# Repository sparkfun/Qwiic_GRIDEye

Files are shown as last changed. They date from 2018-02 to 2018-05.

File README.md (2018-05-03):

SparkFun Qwiic Panasonic Grid-EYE Infrared Array AMG88xx
========================================

SparkFun Grid-EYE Infrared Array Breakout - AMG8833 (Qwiic)

[*SparkFun Grid-EYE Infrared Array Breakout - AMG8833 (Qwiic) (SEN-14607)*](https://www.sparkfun.com/products/14607)

The GridEYE from Panasonic is a 8 by 8 thermopile array. This means you have an array of 64 pixels each capable of detecting temperature remotely. It’s like having thermal camera (or Predator’s vision) just in really low resolution. The SparkFun Grid-EYE Qwiic carrier board utilizes the high performance, high gain 3.3V AMG88 sensor. Do not hook 5V to this beast! Better yet, use the Qwiic system - it makes it much easier and quicker to get started.

The SparkFun carrier board incorporates all the needed passive components as well as a jumper to change the I2C address and a jumper to remove the pull up resistors if needed.

Repository Contents
-------------------

* **/Documents** - Datasheets
* **/Hardware** - Eagle design files (.brd, .sch)

Documentation
--------------
* **[Arduino Library](https://github.com/sparkfun/SparkFun_GridEYE_Arduino_Library)** - Library for reading the sensor and outputing fun graphics over the serial port
* **[Hookup Guide](https://learn.sparkfun.com/tutorials/qwiic-grid-eye-infrared-array-amg88xx-hookup-guide)** - Basic hookup guide for the Qwiic GRID-Eye Infrared Array.

Product Versions
----------------
* [SEN-14607](https://www.sparkfun.com/products/14607)- SparkFun breakout board for Grid-EYE AMG8833
* [SPX-14568](https://www.sparkfun.com/products/14568)- SparkX breakout board for Grid-EYE AMG8833

License Information
-------------------

This product is _**open source**_! 

Please review the LICENSE.md file for license information. 

If you have any questions or concerns on licensing, please contact techsupport@sparkfun.com.

Please use, reuse, and modify these files as you see fit. Please maintain attribution to SparkFun Electronics and release anyThing Development Board derivative under the same license.

Distributed as-is; no warranty is given.

- Your friends at SparkFun.

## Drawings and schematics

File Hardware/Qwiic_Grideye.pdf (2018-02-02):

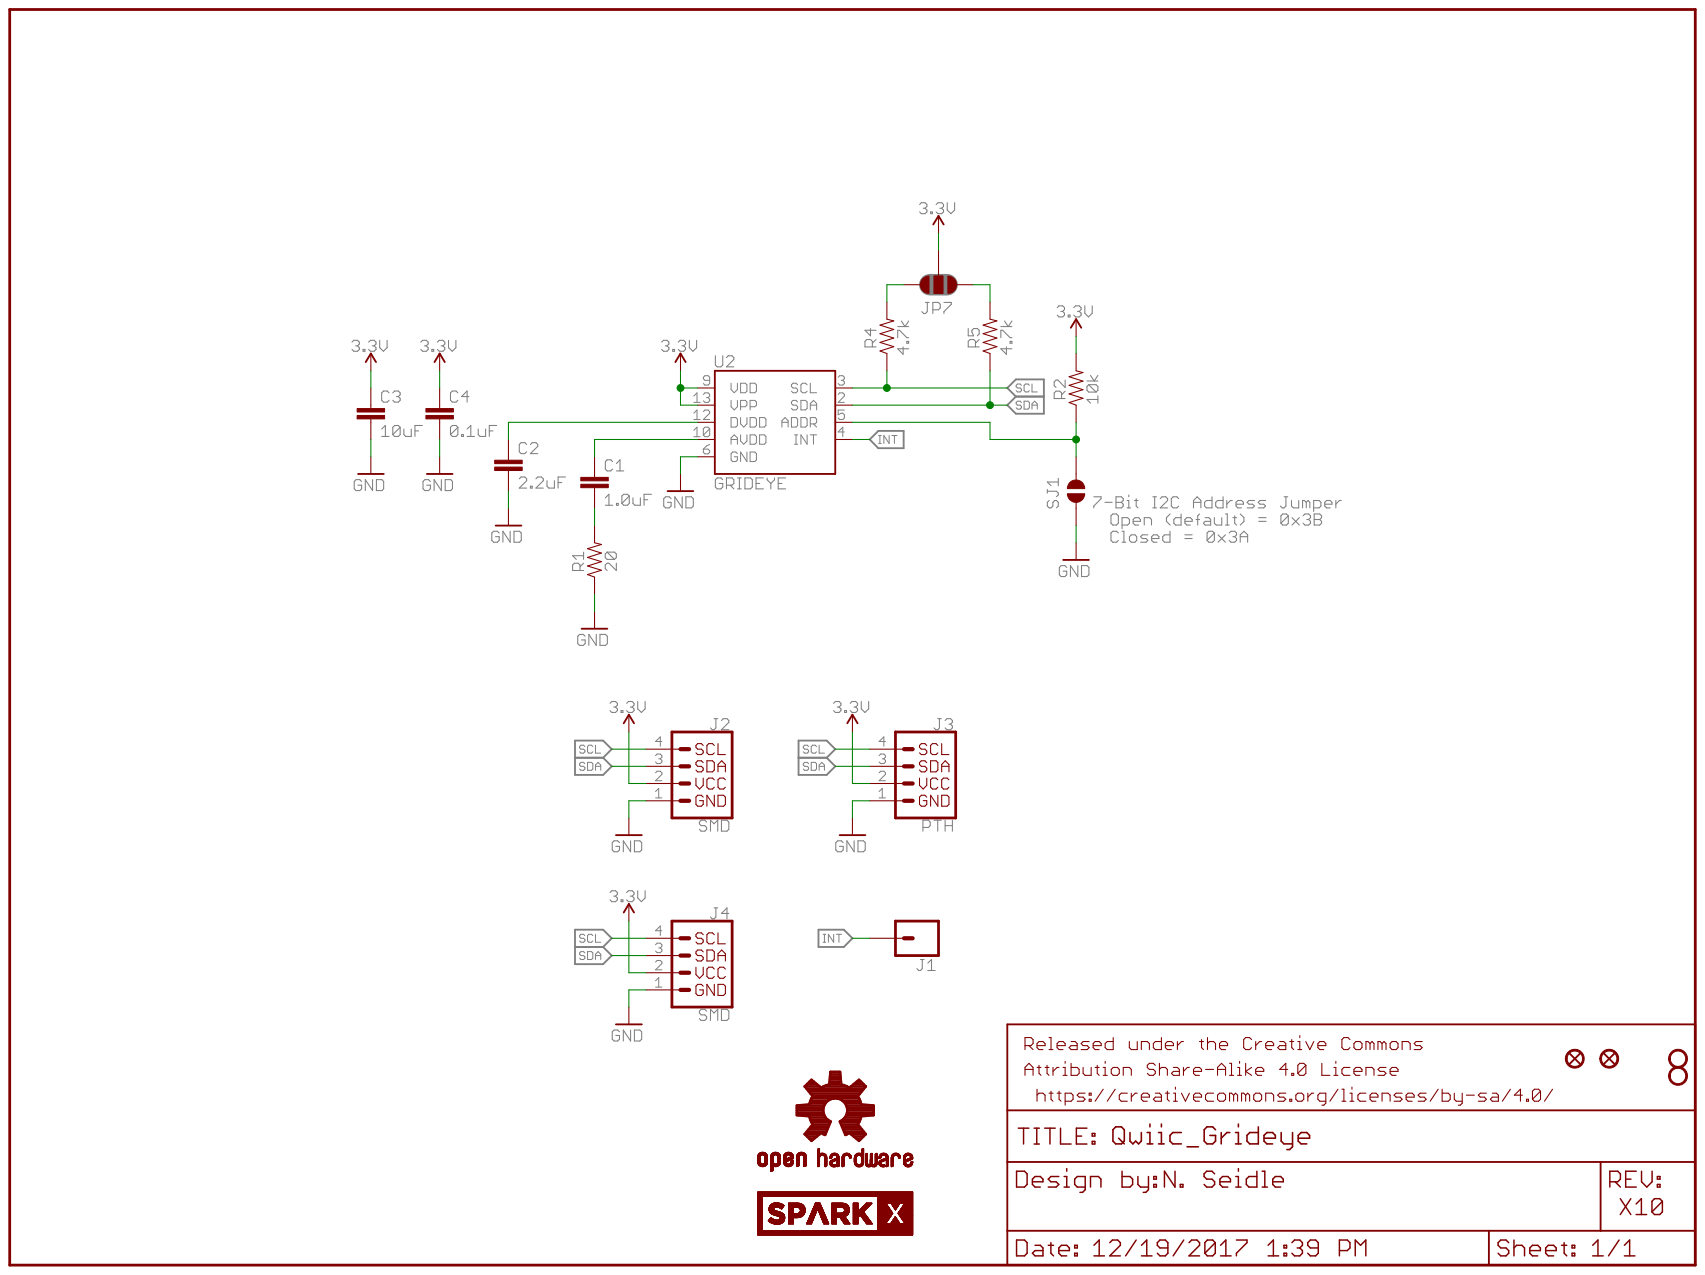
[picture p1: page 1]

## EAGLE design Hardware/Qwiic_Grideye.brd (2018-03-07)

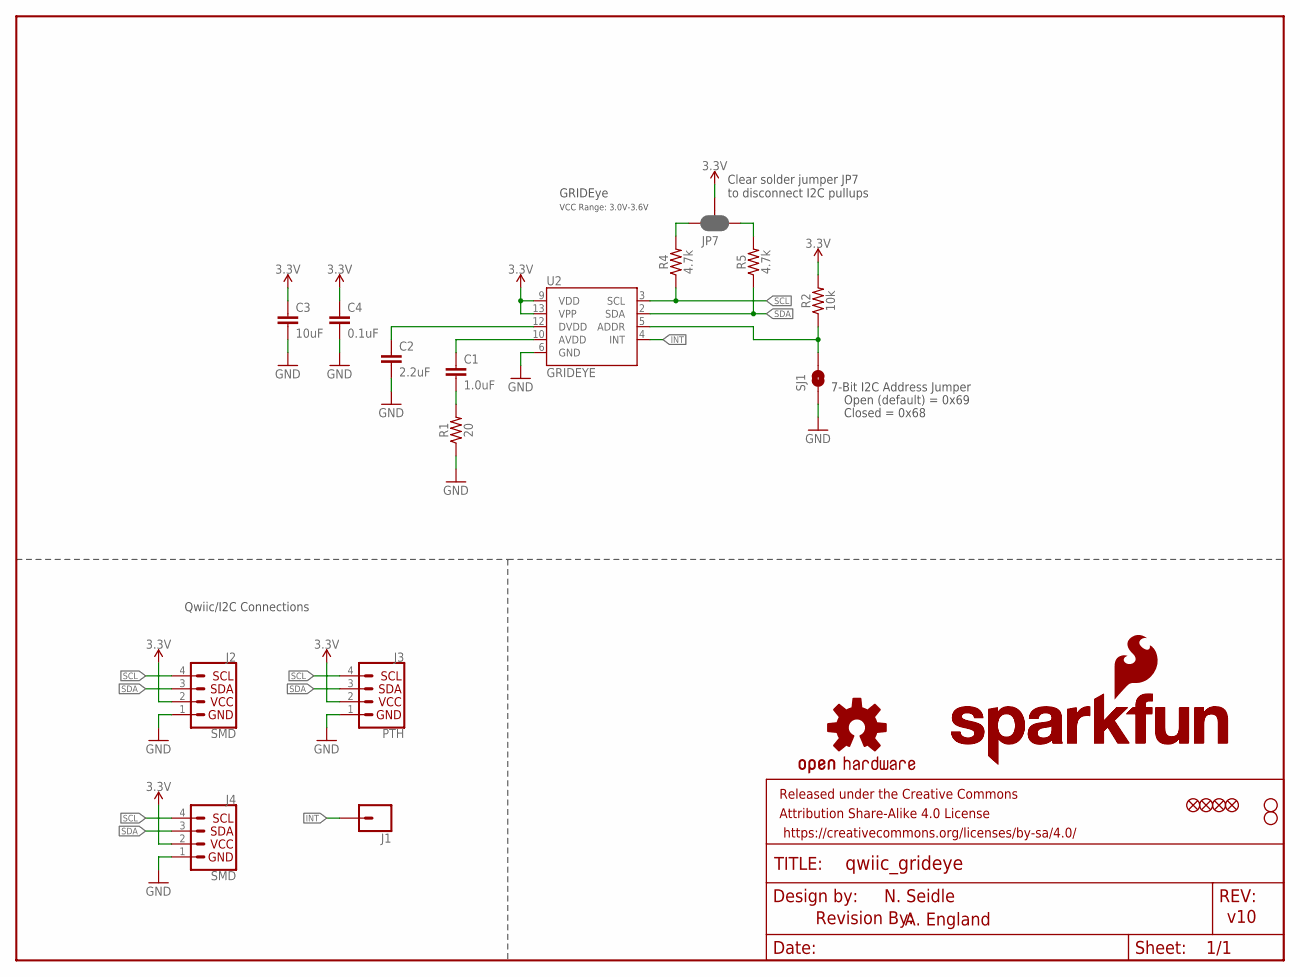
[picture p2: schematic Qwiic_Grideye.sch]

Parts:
C1: 1.0uF; 0603
C2: 2.2uF; 0603
C3: 10uF; 0603
C4: 0.1uF; 0603
FRAME1: FRAME-LETTER; CREATIVE_COMMONS
J1: CONN_01PTH_NO_SILK_YES_STOP; 1X01_NO_SILK
J2, J4: SMD; 1X04_1MM_RA
J3: PTH; 1X04_NO_SILK
JP1, JP2, JP5, JP6: FIDUCIALUFIDUCIAL; MICRO-FIDUCIAL
JP3, JP4: STAND-OFF
JP7: JUMPER-SMT_3_2-NC_PASTE_SILK; SMT-JUMPER_3_2-NC_PASTE_SILK
LOGO1: OSHW-LOGOMINI; OSHW-LOGO-MINI
LOGO2: REVISION
R1: 20; 0603
R2: 10k; 0603
R4, R5: 4.7k; 0603
SJ1: SOLDERJUMPERNO; SJ_2S-NO
U2: GRIDEYE; GRIDEYE-AMG88
U$1: SFE_LOGO_NAME.1_INCH; SFE_LOGO_NAME_.1
U$2: SFE_LOGO_NAME_FLAME.1_INCH; SFE_LOGO_NAME_FLAME_.1

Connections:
3.3V: C3.1, C4.1, J2.2 (VCC), J3.2 (VCC), J4.2 (VCC), JP7.2, R2.2, U2.9 (VDD), U2.13 (VPP)
ADDR: R2.1, SJ1.2, U2.5 (ADDR)
GND: C2.2, C3.2, C4.2, J2.1 (GND), J3.1 (GND), J4.1 (GND), R1.1, SJ1.1, U2.6 (GND)
INT: J1.1, U2.4 (INT)
unnamed: JP7.1, R5.2
unnamed: JP7.3, R4.2
unnamed: C2.1, U2.12 (DVDD)
unnamed: C1.1, U2.10 (AVDD)
unnamed: C1.2, R1.2
SCL: J2.4 (SCL), J3.4 (SCL), J4.4 (SCL), R4.1, U2.3 (SCL)
SDA: J2.3 (SDA), J3.3 (SDA), J4.3 (SDA), R5.1, U2.2 (SDA)

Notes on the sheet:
7-Bit I2C Address Jumper
Closed = 0x68
Open (default) = 0x69
N. Seidle
v10
GRIDEye
Clear solder jumper JP7 to disconnect I2C pullups
Qwiic/I2C Connections
A. England
VCC Range: 3.0V-3.6V

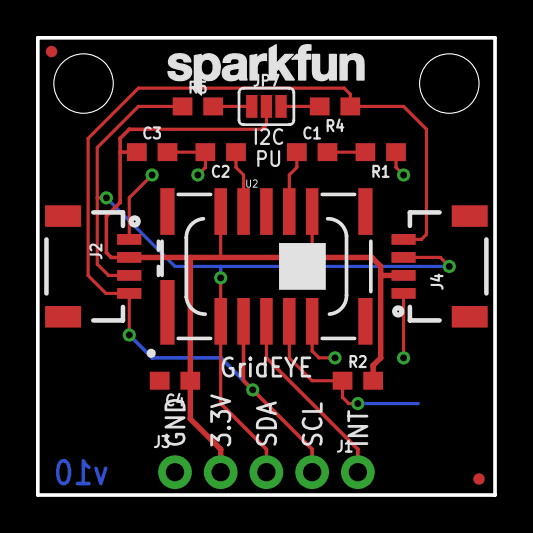
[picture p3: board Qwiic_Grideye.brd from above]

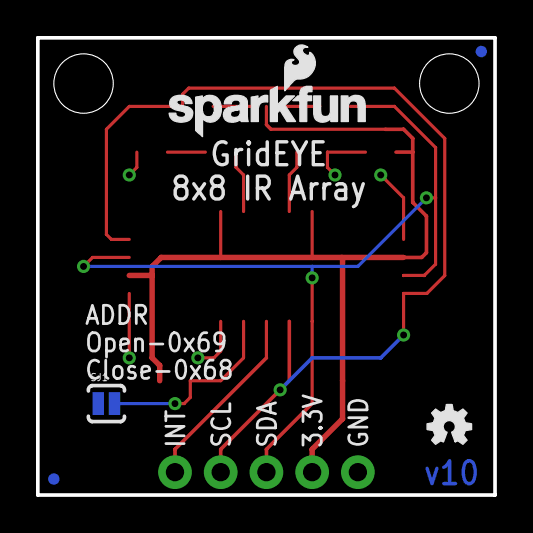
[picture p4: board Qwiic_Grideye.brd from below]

Board: 2 copper layers, 25.4 x 25.4 mm, 26 parts (5 on the bottom side), 11 nets.

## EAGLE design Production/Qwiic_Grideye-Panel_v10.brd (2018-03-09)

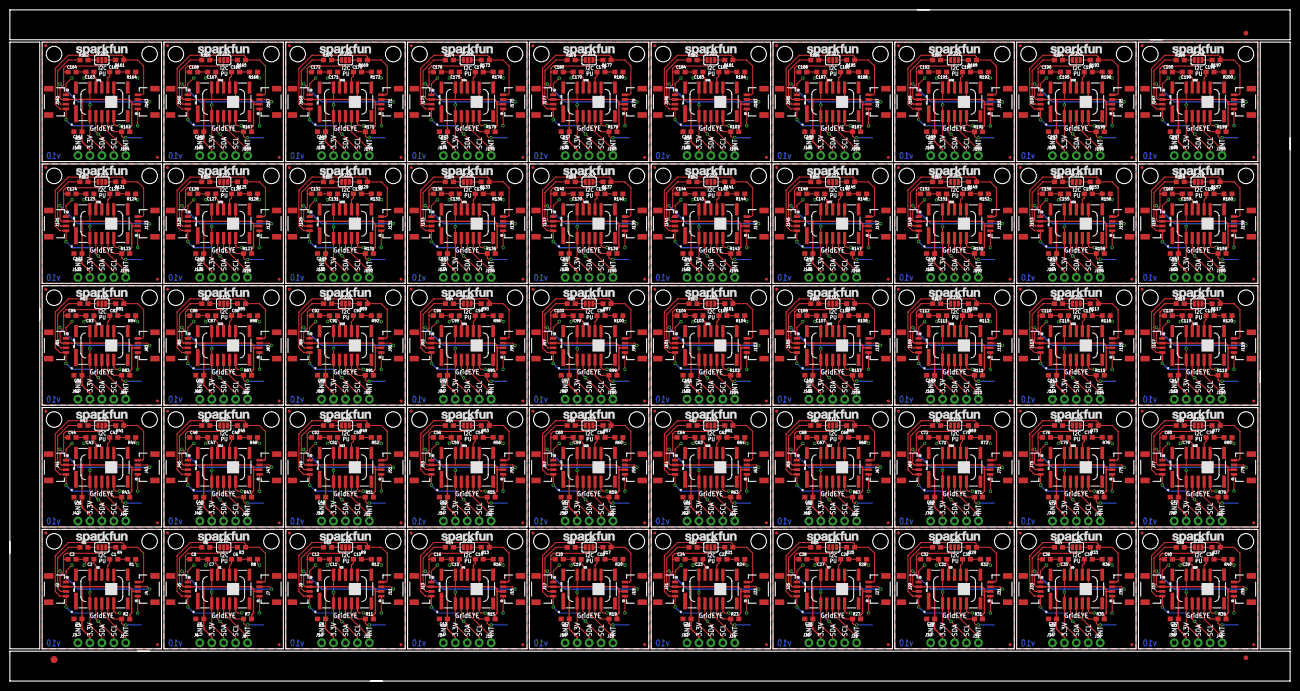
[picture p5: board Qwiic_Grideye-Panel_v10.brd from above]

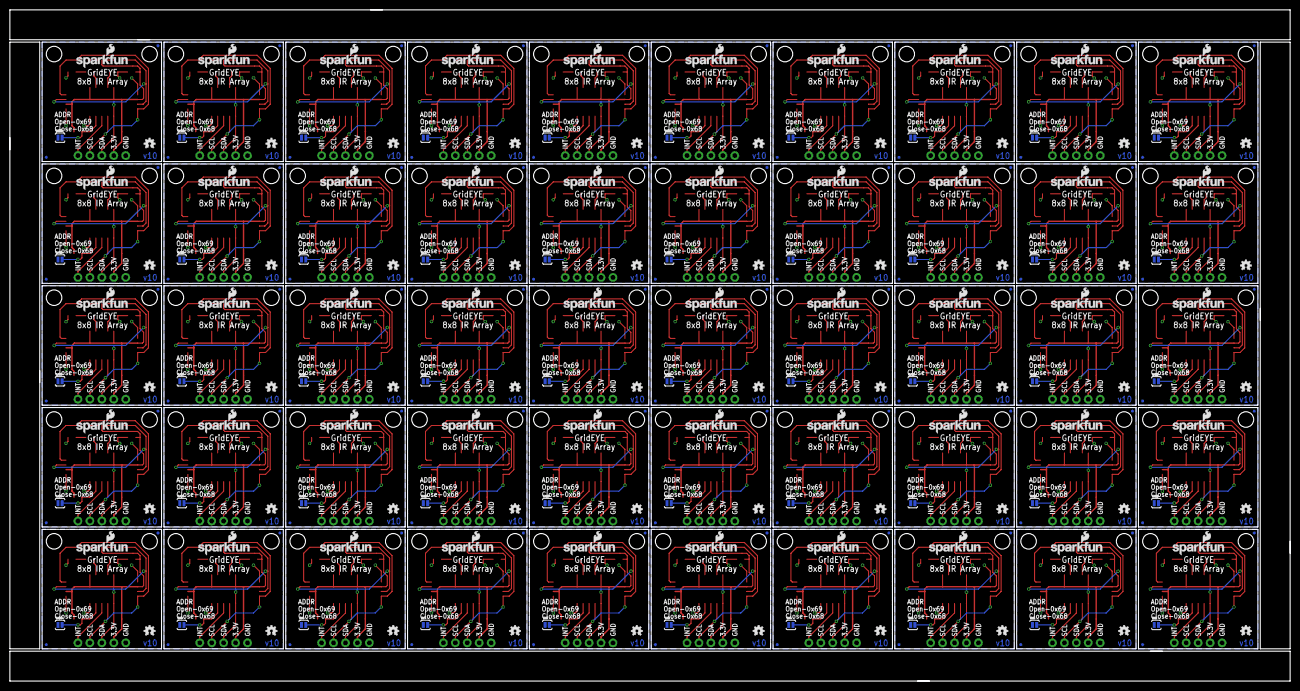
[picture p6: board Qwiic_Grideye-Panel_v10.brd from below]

Board: 2 copper layers, 272.3 x 142.7 mm, 1203 parts (250 on the bottom side), 550 nets.

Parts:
C1, C6, C10, C14, C18, C22, C26, C30, C34, C38, C42, C46, C50, C54, C58, C62, C66, C70, C74, C78, C82, C86, C90, C94, C98, C102, C106, C110, C114, C118, C122, C126, C130, C134, C138, C142, C146, C150, C154, C158, C162, C166, C170, C174, C178, C182, C186, C190, C194, C198: 1.0uF; 0603
C2, C7, C11, C15, C19, C23, C27, C31, C35, C39, C43, C47, C51, C55, C59, C63, C67, C71, C75, C79, C83, C87, C91, C95, C99, C103, C107, C111, C115, C119, C123, C127, C131, C135, C139, C143, C147, C151, C155, C159, C163, C167, C171, C175, C179, C183, C187, C191, C195, C199: 2.2uF; 0603
C3, C8, C12, C16, C20, C24, C28, C32, C36, C40, C44, C48, C52, C56, C60, C64, C68, C72, C76, C80, C84, C88, C92, C96, C100, C104, C108, C112, C116, C120, C124, C128, C132, C136, C140, C144, C148, C152, C156, C160, C164, C168, C172, C176, C180, C184, C188, C192, C196, C200: 10uF; 0603
C4, C5, C9, C13, C17, C21, C25, C29, C33, C37, C41, C45, C49, C53, C57, C61, C65, C69, C73, C77, C81, C85, C89, C93, C97, C101, C105, C109, C113, C117, C121, C125, C129, C133, C137, C141, C145, C149, C153, C157, C161, C165, C169, C173, C177, C181, C185, C189, C193, C197: 0.1uF; 0603
E$1: FIDUCIAL-1.5X3
E$5, E$8: FIDUCIAL-1X2
J1, J8, J12, J16, J20, J24, J28, J32, J36, J40, J44, J48, J52, J56, J60, J64, J68, J72, J76, J80, J84, J88, J92, J96, J100, J104, J108, J112, J116, J120, J124, J128, J132, J136, J140, J144, J148, J152, J156, J160, J164, J168, J172, J176, J180, J184, J188, J192, J196, J200: 1X01_NO_SILK
J2, J4, J5, J7, J9, J11, J13, J15, J17, J19, J21, J23, J25, J27, J29, J31, J33, J35, J37, J39, J41, J43, J45, J47, J49, J51, J53, J55, J57, J59, J61, J63, J65, J67, J69, J71, J73, J75, J77, J79, J81, J83, J85, J87, J89, J91, J93, J95, J97, J99, J101, J103, J105, J107, J109, J111, J113, J115, J117, J119, J121, J123, J125, J127, J129, J131, J133, J135, J137, J139, J141, J143, J145, J147, J149, J151, J153, J155, J157, J159, J161, J163, J165, J167, J169, J171, J173, J175, J177, J179, J181, J183, J185, J187, J189, J191, J193, J195, J197, J199: SMD; 1X04_1MM_RA
J3, J6, J10, J14, J18, J22, J26, J30, J34, J38, J42, J46, J50, J54, J58, J62, J66, J70, J74, J78, J82, J86, J90, J94, J98, J102, J106, J110, J114, J118, J122, J126, J130, J134, J138, J142, J146, J150, J154, J158, J162, J166, J170, J174, J178, J182, J186, J190, J194, J198: PTH; 1X04_NO_SILK
JP1, JP2, JP5, JP6, JP10, JP11, JP13, JP14, JP17, JP18, JP20, JP21, JP24, JP25, JP27, JP28, JP31, JP32, JP34, JP35, JP38, JP39, JP41, JP42, JP45, JP46, JP48, JP49, JP52, JP53, JP55, JP56, JP59, JP60, JP62, JP63, JP66, JP67, JP69, JP70, JP73, JP74, JP76, JP77, JP80, JP81, JP83, JP84, JP87, JP88, JP90, JP91, JP94, JP95, JP97, JP98, JP101, JP102, JP104, JP105, JP108, JP109, JP111, JP112, JP115, JP116, JP118, JP119, JP122, JP123, JP125, JP126, JP129, JP130, JP132, JP133, JP136, JP137, JP139, JP140, JP143, JP144, JP146, JP147, JP150, JP151, JP153, JP154, JP157, JP158, JP160, JP161, JP164, JP165, JP167, JP168, JP171, JP172, JP174, JP175, JP178, JP179, JP181, JP182, JP185, JP186, JP188, JP189, JP192, JP193, JP195, JP196, JP199, JP200, JP202, JP203, JP206, JP207, JP209, JP210, JP213, JP214, JP216, JP217, JP220, JP221, JP223, JP224, JP227, JP228, JP230, JP231, JP234, JP235, JP237, JP238, JP241, JP242, JP244, JP245, JP248, JP249, JP251, JP252, JP255, JP256, JP258, JP259, JP262, JP263, JP265, JP266, JP269, JP270, JP272, JP273, JP276, JP277, JP279, JP280, JP283, JP284, JP286, JP287, JP290, JP291, JP293, JP294, JP297, JP298, JP300, JP301, JP304, JP305, JP307, JP308, JP311, JP312, JP314, JP315, JP318, JP319, JP321, JP322, JP325, JP326, JP328, JP329, JP332, JP333, JP335, JP336, JP339, JP340, JP342, JP343, JP346, JP347, JP349, JP350: FIDUCIALUFIDUCIAL; MICRO-FIDUCIAL
JP3, JP4, JP8, JP9, JP15, JP16, JP22, JP23, JP29, JP30, JP36, JP37, JP43, JP44, JP50, JP51, JP57, JP58, JP64, JP65, JP71, JP72, JP78, JP79, JP85, JP86, JP92, JP93, JP99, JP100, JP106, JP107, JP113, JP114, JP120, JP121, JP127, JP128, JP134, JP135, JP141, JP142, JP148, JP149, JP155, JP156, JP162, JP163, JP169, JP170, JP176, JP177, JP183, JP184, JP190, JP191, JP197, JP198, JP204, JP205, JP211, JP212, JP218, JP219, JP225, JP226, JP232, JP233, JP239, JP240, JP246, JP247, JP253, JP254, JP260, JP261, JP267, JP268, JP274, JP275, JP281, JP282, JP288, JP289, JP295, JP296, JP302, JP303, JP309, JP310, JP316, JP317, JP323, JP324, JP330, JP331, JP337, JP338, JP344, JP345: STAND-OFF
JP7, JP12, JP19, JP26, JP33, JP40, JP47, JP54, JP61, JP68, JP75, JP82, JP89, JP96, JP103, JP110, JP117, JP124, JP131, JP138, JP145, JP152, JP159, JP166, JP173, JP180, JP187, JP194, JP201, JP208, JP215, JP222, JP229, JP236, JP243, JP250, JP257, JP264, JP271, JP278, JP285, JP292, JP299, JP306, JP313, JP320, JP327, JP334, JP341, JP348: SMT-JUMPER_3_2-NC_PASTE_SILK
LOGO1, LOGO2, LOGO3, LOGO4, LOGO5, LOGO6, LOGO7, LOGO8, LOGO9, LOGO10, LOGO11, LOGO12, LOGO13, LOGO14, LOGO15, LOGO16, LOGO17, LOGO18, LOGO19, LOGO20, LOGO21, LOGO22, LOGO23, LOGO24, LOGO25, LOGO26, LOGO27, LOGO28, LOGO29, LOGO30, LOGO31, LOGO32, LOGO33, LOGO34, LOGO35, LOGO36, LOGO37, LOGO38, LOGO39, LOGO40, LOGO41, LOGO42, LOGO43, LOGO44, LOGO45, LOGO46, LOGO47, LOGO48, LOGO49, LOGO50: OSHW-LOGOMINI; OSHW-LOGO-MINI
R1, R8, R12, R16, R20, R24, R28, R32, R36, R40, R44, R48, R52, R56, R60, R64, R68, R72, R76, R80, R84, R88, R92, R96, R100, R104, R108, R112, R116, R120, R124, R128, R132, R136, R140, R144, R148, R152, R156, R160, R164, R168, R172, R176, R180, R184, R188, R192, R196, R200: 20; 0603
R2, R7, R11, R15, R19, R23, R27, R31, R35, R39, R43, R47, R51, R55, R59, R63, R67, R71, R75, R79, R83, R87, R91, R95, R99, R103, R107, R111, R115, R119, R123, R127, R131, R135, R139, R143, R147, R151, R155, R159, R163, R167, R171, R175, R179, R183, R187, R191, R195, R199: 10k; 0603
R3, R4, R5, R6, R9, R10, R13, R14, R17, R18, R21, R22, R25, R26, R29, R30, R33, R34, R37, R38, R41, R42, R45, R46, R49, R50, R53, R54, R57, R58, R61, R62, R65, R66, R69, R70, R73, R74, R77, R78, R81, R82, R85, R86, R89, R90, R93, R94, R97, R98, R101, R102, R105, R106, R109, R110, R113, R114, R117, R118, R121, R122, R125, R126, R129, R130, R133, R134, R137, R138, R141, R142, R145, R146, R149, R150, R153, R154, R157, R158, R161, R162, R165, R166, R169, R170, R173, R174, R177, R178, R181, R182, R185, R186, R189, R190, R193, R194, R197, R198: 4.7k; 0603
SJ1, SJ2, SJ3, SJ4, SJ5, SJ6, SJ7, SJ8, SJ9, SJ10, SJ11, SJ12, SJ13, SJ14, SJ15, SJ16, SJ17, SJ18, SJ19, SJ20, SJ21, SJ22, SJ23, SJ24, SJ25, SJ26, SJ27, SJ28, SJ29, SJ30, SJ31, SJ32, SJ33, SJ34, SJ35, SJ36, SJ37, SJ38, SJ39, SJ40, SJ41, SJ42, SJ43, SJ44, SJ45, SJ46, SJ47, SJ48, SJ49, SJ50: SJ_2S-NO
U1, U2, U3, U4, U5, U6, U7, U8, U9, U10, U11, U12, U13, U14, U15, U16, U17, U18, U19, U20, U21, U22, U23, U24, U25, U26, U27, U28, U29, U30, U31, U32, U33, U34, U35, U36, U37, U38, U39, U40, U41, U42, U43, U44, U45, U46, U47, U48, U49, U50: GRIDEYE; GRIDEYE-AMG88
U$1, U$4, U$6, U$8, U$10, U$12, U$14, U$16, U$18, U$20, U$22, U$24, U$26, U$28, U$30, U$32, U$34, U$36, U$38, U$40, U$42, U$44, U$46, U$48, U$50, U$52, U$54, U$56, U$58, U$60, U$62, U$64, U$66, U$68, U$70, U$72, U$74, U$76, U$78, U$80, U$82, U$84, U$86, U$88, U$90, U$92, U$94, U$96, U$98, U$100: SFE_LOGO_NAME.1_INCH; SFE_LOGO_NAME_.1
U$2, U$3, U$5, U$7, U$9, U$11, U$13, U$15, U$17, U$19, U$21, U$23, U$25, U$27, U$29, U$31, U$33, U$35, U$37, U$39, U$41, U$43, U$45, U$47, U$49, U$51, U$53, U$55, U$57, U$59, U$61, U$63, U$65, U$67, U$69, U$71, U$73, U$75, U$77, U$79, U$81, U$83, U$85, U$87, U$89, U$91, U$93, U$95, U$97, U$99: SFE_LOGO_NAME_FLAME.1_INCH; SFE_LOGO_NAME_FLAME_.1

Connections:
3.3V: C3.1, C4.1, J2.2, J3.2, J4.2, JP7.2, R2.2, U2.9, U2.13
3.3V1: C5.1, C8.1, J5.2, J6.2, J7.2, JP12.2, R7.2, U1.9, U1.13
3.3V2: C9.1, C12.1, J9.2, J10.2, J11.2, JP19.2, R11.2, U3.9, U3.13
3.3V3: C13.1, C16.1, J13.2, J14.2, J15.2, JP26.2, R15.2, U4.9, U4.13
3.3V4: C17.1, C20.1, J17.2, J18.2, J19.2, JP33.2, R19.2, U5.9, U5.13
3.3V5: C21.1, C24.1, J21.2, J22.2, J23.2, JP40.2, R23.2, U6.9, U6.13
3.3V6: C25.1, C28.1, J25.2, J26.2, J27.2, JP47.2, R27.2, U7.9, U7.13
3.3V7: C29.1, C32.1, J29.2, J30.2, J31.2, JP54.2, R31.2, U8.9, U8.13
3.3V8: C33.1, C36.1, J33.2, J34.2, J35.2, JP61.2, R35.2, U9.9, U9.13
3.3V9: C37.1, C40.1, J37.2, J38.2, J39.2, JP68.2, R39.2, U10.9, U10.13
3.3V10: C41.1, C44.1, J41.2, J42.2, J43.2, JP75.2, R43.2, U11.9, U11.13
3.3V11: C45.1, C48.1, J45.2, J46.2, J47.2, JP82.2, R47.2, U12.9, U12.13
3.3V12: C49.1, C52.1, J49.2, J50.2, J51.2, JP89.2, R51.2, U13.9, U13.13
3.3V13: C53.1, C56.1, J53.2, J54.2, J55.2, JP96.2, R55.2, U14.9, U14.13
3.3V14: C57.1, C60.1, J57.2, J58.2, J59.2, JP103.2, R59.2, U15.9, U15.13
3.3V15: C61.1, C64.1, J61.2, J62.2, J63.2, JP110.2, R63.2, U16.9, U16.13
3.3V16: C65.1, C68.1, J65.2, J66.2, J67.2, JP117.2, R67.2, U17.9, U17.13
3.3V17: C69.1, C72.1, J69.2, J70.2, J71.2, JP124.2, R71.2, U18.9, U18.13
3.3V18: C73.1, C76.1, J73.2, J74.2, J75.2, JP131.2, R75.2, U19.9, U19.13
3.3V19: C77.1, C80.1, J77.2, J78.2, J79.2, JP138.2, R79.2, U20.9, U20.13
3.3V20: C81.1, C84.1, J81.2, J82.2, J83.2, JP145.2, R83.2, U21.9, U21.13
3.3V21: C85.1, C88.1, J85.2, J86.2, J87.2, JP152.2, R87.2, U22.9, U22.13
3.3V22: C89.1, C92.1, J89.2, J90.2, J91.2, JP159.2, R91.2, U23.9, U23.13
3.3V23: C93.1, C96.1, J93.2, J94.2, J95.2, JP166.2, R95.2, U24.9, U24.13
3.3V24: C97.1, C100.1, J97.2, J98.2, J99.2, JP173.2, R99.2, U25.9, U25.13
3.3V25: C101.1, C104.1, J101.2, J102.2, J103.2, JP180.2, R103.2, U26.9, U26.13
3.3V26: C105.1, C108.1, J105.2, J106.2, J107.2, JP187.2, R107.2, U27.9, U27.13
3.3V27: C109.1, C112.1, J109.2, J110.2, J111.2, JP194.2, R111.2, U28.9, U28.13
3.3V28: C113.1, C116.1, J113.2, J114.2, J115.2, JP201.2, R115.2, U29.9, U29.13
3.3V29: C117.1, C120.1, J117.2, J118.2, J119.2, JP208.2, R119.2, U30.9, U30.13
3.3V30: C121.1, C124.1, J121.2, J122.2, J123.2, JP215.2, R123.2, U31.9, U31.13
3.3V31: C125.1, C128.1, J125.2, J126.2, J127.2, JP222.2, R127.2, U32.9, U32.13
3.3V32: C129.1, C132.1, J129.2, J130.2, J131.2, JP229.2, R131.2, U33.9, U33.13
3.3V33: C133.1, C136.1, J133.2, J134.2, J135.2, JP236.2, R135.2, U34.9, U34.13
3.3V34: C137.1, C140.1, J137.2, J138.2, J139.2, JP243.2, R139.2, U35.9, U35.13
3.3V35: C141.1, C144.1, J141.2, J142.2, J143.2, JP250.2, R143.2, U36.9, U36.13
3.3V36: C145.1, C148.1, J145.2, J146.2, J147.2, JP257.2, R147.2, U37.9, U37.13
3.3V37: C149.1, C152.1, J149.2, J150.2, J151.2, JP264.2, R151.2, U38.9, U38.13
3.3V38: C153.1, C156.1, J153.2, J154.2, J155.2, JP271.2, R155.2, U39.9, U39.13
3.3V39: C157.1, C160.1, J157.2, J158.2, J159.2, JP278.2, R159.2, U40.9, U40.13
3.3V40: C161.1, C164.1, J161.2, J162.2, J163.2, JP285.2, R163.2, U41.9, U41.13
3.3V41: C165.1, C168.1, J165.2, J166.2, J167.2, JP292.2, R167.2, U42.9, U42.13
3.3V42: C169.1, C172.1, J169.2, J170.2, J171.2, JP299.2, R171.2, U43.9, U43.13
3.3V43: C173.1, C176.1, J173.2, J174.2, J175.2, JP306.2, R175.2, U44.9, U44.13
3.3V44: C177.1, C180.1, J177.2, J178.2, J179.2, JP313.2, R179.2, U45.9, U45.13
3.3V45: C181.1, C184.1, J181.2, J182.2, J183.2, JP320.2, R183.2, U46.9, U46.13
3.3V46: C185.1, C188.1, J185.2, J186.2, J187.2, JP327.2, R187.2, U47.9, U47.13
3.3V47: C189.1, C192.1, J189.2, J190.2, J191.2, JP334.2, R191.2, U48.9, U48.13
3.3V48: C193.1, C196.1, J193.2, J194.2, J195.2, JP341.2, R195.2, U49.9, U49.13
3.3V49: C197.1, C200.1, J197.2, J198.2, J199.2, JP348.2, R199.2, U50.9, U50.13
ADDR: R2.1, SJ1.2, U2.5
ADDR1: R7.1, SJ2.2, U1.5
ADDR2: R11.1, SJ3.2, U3.5
ADDR3: R15.1, SJ4.2, U4.5
ADDR4: R19.1, SJ5.2, U5.5
ADDR5: R23.1, SJ6.2, U6.5
ADDR6: R27.1, SJ7.2, U7.5
ADDR7: R31.1, SJ8.2, U8.5
ADDR8: R35.1, SJ9.2, U9.5
ADDR9: R39.1, SJ10.2, U10.5
ADDR10: R43.1, SJ11.2, U11.5
ADDR11: R47.1, SJ12.2, U12.5
ADDR12: R51.1, SJ13.2, U13.5
ADDR13: R55.1, SJ14.2, U14.5
ADDR14: R59.1, SJ15.2, U15.5
ADDR15: R63.1, SJ16.2, U16.5
ADDR16: R67.1, SJ17.2, U17.5
ADDR17: R71.1, SJ18.2, U18.5
ADDR18: R75.1, SJ19.2, U19.5
ADDR19: R79.1, SJ20.2, U20.5
ADDR20: R83.1, SJ21.2, U21.5
ADDR21: R87.1, SJ22.2, U22.5
ADDR22: R91.1, SJ23.2, U23.5
ADDR23: R95.1, SJ24.2, U24.5
ADDR24: R99.1, SJ25.2, U25.5
ADDR25: R103.1, SJ26.2, U26.5
ADDR26: R107.1, SJ27.2, U27.5
ADDR27: R111.1, SJ28.2, U28.5
ADDR28: R115.1, SJ29.2, U29.5
ADDR29: R119.1, SJ30.2, U30.5
ADDR30: R123.1, SJ31.2, U31.5
ADDR31: R127.1, SJ32.2, U32.5
ADDR32: R131.1, SJ33.2, U33.5
ADDR33: R135.1, SJ34.2, U34.5
ADDR34: R139.1, SJ35.2, U35.5
ADDR35: R143.1, SJ36.2, U36.5
ADDR36: R147.1, SJ37.2, U37.5
ADDR37: R151.1, SJ38.2, U38.5
ADDR38: R155.1, SJ39.2, U39.5
ADDR39: R159.1, SJ40.2, U40.5
ADDR40: R163.1, SJ41.2, U41.5
ADDR41: R167.1, SJ42.2, U42.5
ADDR42: R171.1, SJ43.2, U43.5
ADDR43: R175.1, SJ44.2, U44.5
ADDR44: R179.1, SJ45.2, U45.5
ADDR45: R183.1, SJ46.2, U46.5
ADDR46: R187.1, SJ47.2, U47.5
ADDR47: R191.1, SJ48.2, U48.5
ADDR48: R195.1, SJ49.2, U49.5
ADDR49: R199.1, SJ50.2, U50.5
GND: C2.2, C3.2, C4.2, J2.1, J3.1, J4.1, R1.1, SJ1.1, U2.6
GND1: C5.2, C7.2, C8.2, J5.1, J6.1, J7.1, R8.1, SJ2.1, U1.6
GND2: C9.2, C11.2, C12.2, J9.1, J10.1, J11.1, R12.1, SJ3.1, U3.6
GND3: C13.2, C15.2, C16.2, J13.1, J14.1, J15.1, R16.1, SJ4.1, U4.6
GND4: C17.2, C19.2, C20.2, J17.1, J18.1, J19.1, R20.1, SJ5.1, U5.6
GND5: C21.2, C23.2, C24.2, J21.1, J22.1, J23.1, R24.1, SJ6.1, U6.6
GND6: C25.2, C27.2, C28.2, J25.1, J26.1, J27.1, R28.1, SJ7.1, U7.6
GND7: C29.2, C31.2, C32.2, J29.1, J30.1, J31.1, R32.1, SJ8.1, U8.6
GND8: C33.2, C35.2, C36.2, J33.1, J34.1, J35.1, R36.1, SJ9.1, U9.6
GND9: C37.2, C39.2, C40.2, J37.1, J38.1, J39.1, R40.1, SJ10.1, U10.6
GND10: C41.2, C43.2, C44.2, J41.1, J42.1, J43.1, R44.1, SJ11.1, U11.6
GND11: C45.2, C47.2, C48.2, J45.1, J46.1, J47.1, R48.1, SJ12.1, U12.6
GND12: C49.2, C51.2, C52.2, J49.1, J50.1, J51.1, R52.1, SJ13.1, U13.6
GND13: C53.2, C55.2, C56.2, J53.1, J54.1, J55.1, R56.1, SJ14.1, U14.6
GND14: C57.2, C59.2, C60.2, J57.1, J58.1, J59.1, R60.1, SJ15.1, U15.6
GND15: C61.2, C63.2, C64.2, J61.1, J62.1, J63.1, R64.1, SJ16.1, U16.6
GND16: C65.2, C67.2, C68.2, J65.1, J66.1, J67.1, R68.1, SJ17.1, U17.6
GND17: C69.2, C71.2, C72.2, J69.1, J70.1, J71.1, R72.1, SJ18.1, U18.6
GND18: C73.2, C75.2, C76.2, J73.1, J74.1, J75.1, R76.1, SJ19.1, U19.6
GND19: C77.2, C79.2, C80.2, J77.1, J78.1, J79.1, R80.1, SJ20.1, U20.6
GND20: C81.2, C83.2, C84.2, J81.1, J82.1, J83.1, R84.1, SJ21.1, U21.6
GND21: C85.2, C87.2, C88.2, J85.1, J86.1, J87.1, R88.1, SJ22.1, U22.6
GND22: C89.2, C91.2, C92.2, J89.1, J90.1, J91.1, R92.1, SJ23.1, U23.6
GND23: C93.2, C95.2, C96.2, J93.1, J94.1, J95.1, R96.1, SJ24.1, U24.6
GND24: C97.2, C99.2, C100.2, J97.1, J98.1, J99.1, R100.1, SJ25.1, U25.6
GND25: C101.2, C103.2, C104.2, J101.1, J102.1, J103.1, R104.1, SJ26.1, U26.6
GND26: C105.2, C107.2, C108.2, J105.1, J106.1, J107.1, R108.1, SJ27.1, U27.6
GND27: C109.2, C111.2, C112.2, J109.1, J110.1, J111.1, R112.1, SJ28.1, U28.6
GND28: C113.2, C115.2, C116.2, J113.1, J114.1, J115.1, R116.1, SJ29.1, U29.6
GND29: C117.2, C119.2, C120.2, J117.1, J118.1, J119.1, R120.1, SJ30.1, U30.6
GND30: C121.2, C123.2, C124.2, J121.1, J122.1, J123.1, R124.1, SJ31.1, U31.6
GND31: C125.2, C127.2, C128.2, J125.1, J126.1, J127.1, R128.1, SJ32.1, U32.6
GND32: C129.2, C131.2, C132.2, J129.1, J130.1, J131.1, R132.1, SJ33.1, U33.6
GND33: C133.2, C135.2, C136.2, J133.1, J134.1, J135.1, R136.1, SJ34.1, U34.6
GND34: C137.2, C139.2, C140.2, J137.1, J138.1, J139.1, R140.1, SJ35.1, U35.6
GND35: C141.2, C143.2, C144.2, J141.1, J142.1, J143.1, R144.1, SJ36.1, U36.6
GND36: C145.2, C147.2, C148.2, J145.1, J146.1, J147.1, R148.1, SJ37.1, U37.6
GND37: C149.2, C151.2, C152.2, J149.1, J150.1, J151.1, R152.1, SJ38.1, U38.6
GND38: C153.2, C155.2, C156.2, J153.1, J154.1, J155.1, R156.1, SJ39.1, U39.6
GND39: C157.2, C159.2, C160.2, J157.1, J158.1, J159.1, R160.1, SJ40.1, U40.6
GND40: C161.2, C163.2, C164.2, J161.1, J162.1, J163.1, R164.1, SJ41.1, U41.6
GND41: C165.2, C167.2, C168.2, J165.1, J166.1, J167.1, R168.1, SJ42.1, U42.6
GND42: C169.2, C171.2, C172.2, J169.1, J170.1, J171.1, R172.1, SJ43.1, U43.6
GND43: C173.2, C175.2, C176.2, J173.1, J174.1, J175.1, R176.1, SJ44.1, U44.6
GND44: C177.2, C179.2, C180.2, J177.1, J178.1, J179.1, R180.1, SJ45.1, U45.6
GND45: C181.2, C183.2, C184.2, J181.1, J182.1, J183.1, R184.1, SJ46.1, U46.6
GND46: C185.2, C187.2, C188.2, J185.1, J186.1, J187.1, R188.1, SJ47.1, U47.6
GND47: C189.2, C191.2, C192.2, J189.1, J190.1, J191.1, R192.1, SJ48.1, U48.6
GND48: C193.2, C195.2, C196.2, J193.1, J194.1, J195.1, R196.1, SJ49.1, U49.6
GND49: C197.2, C199.2, C200.2, J197.1, J198.1, J199.1, R200.1, SJ50.1, U50.6
INT: J1.1, U2.4
INT1: J8.1, U1.4
INT2: J12.1, U3.4
INT3: J16.1, U4.4
INT4: J20.1, U5.4
INT5: J24.1, U6.4
INT6: J28.1, U7.4
INT7: J32.1, U8.4
INT8: J36.1, U9.4
INT9: J40.1, U10.4
INT10: J44.1, U11.4
INT11: J48.1, U12.4
INT12: J52.1, U13.4
INT13: J56.1, U14.4
INT14: J60.1, U15.4
INT15: J64.1, U16.4
INT16: J68.1, U17.4
INT17: J72.1, U18.4
INT18: J76.1, U19.4
INT19: J80.1, U20.4
INT20: J84.1, U21.4
INT21: J88.1, U22.4
INT22: J92.1, U23.4
INT23: J96.1, U24.4
INT24: J100.1, U25.4
INT25: J104.1, U26.4
INT26: J108.1, U27.4
INT27: J112.1, U28.4
INT28: J116.1, U29.4
INT29: J120.1, U30.4
INT30: J124.1, U31.4
INT31: J128.1, U32.4
INT32: J132.1, U33.4
INT33: J136.1, U34.4
INT34: J140.1, U35.4
INT35: J144.1, U36.4
INT36: J148.1, U37.4
INT37: J152.1, U38.4
INT38: J156.1, U39.4
INT39: J160.1, U40.4
INT40: J164.1, U41.4
INT41: J168.1, U42.4
INT42: J172.1, U43.4
INT43: J176.1, U44.4
INT44: J180.1, U45.4
INT45: J184.1, U46.4
INT46: J188.1, U47.4
INT47: J192.1, U48.4
INT48: J196.1, U49.4
INT49: J200.1, U50.4
unnamed: JP7.1, R5.2
unnamed: JP7.3, R4.2
unnamed: C2.1, U2.12
unnamed: C1.1, U2.10
unnamed: C1.2, R1.2
unnamed: JP12.1, R6.2
unnamed: JP12.3, R3.2
unnamed: C7.1, U1.12
unnamed: C6.1, U1.10
unnamed: C6.2, R8.2
unnamed: JP19.1, R10.2
unnamed: JP19.3, R9.2
unnamed: C11.1, U3.12
unnamed: C10.1, U3.10
unnamed: C10.2, R12.2
unnamed: JP26.1, R14.2
unnamed: JP26.3, R13.2
unnamed: C15.1, U4.12
unnamed: C14.1, U4.10
unnamed: C14.2, R16.2
unnamed: JP33.1, R18.2
unnamed: JP33.3, R17.2
unnamed: C19.1, U5.12
unnamed: C18.1, U5.10
unnamed: C18.2, R20.2
unnamed: JP40.1, R22.2
unnamed: JP40.3, R21.2
unnamed: C23.1, U6.12
unnamed: C22.1, U6.10
unnamed: C22.2, R24.2
unnamed: JP47.1, R26.2
unnamed: JP47.3, R25.2
unnamed: C27.1, U7.12
unnamed: C26.1, U7.10
unnamed: C26.2, R28.2
unnamed: JP54.1, R30.2
unnamed: JP54.3, R29.2
unnamed: C31.1, U8.12
unnamed: C30.1, U8.10
unnamed: C30.2, R32.2
unnamed: JP61.1, R34.2
unnamed: JP61.3, R33.2
unnamed: C35.1, U9.12
unnamed: C34.1, U9.10
unnamed: C34.2, R36.2
unnamed: JP68.1, R38.2
unnamed: JP68.3, R37.2
unnamed: C39.1, U10.12
unnamed: C38.1, U10.10
unnamed: C38.2, R40.2
unnamed: JP75.1, R42.2
unnamed: JP75.3, R41.2
unnamed: C43.1, U11.12
unnamed: C42.1, U11.10
unnamed: C42.2, R44.2
unnamed: JP82.1, R46.2
unnamed: JP82.3, R45.2
unnamed: C47.1, U12.12
unnamed: C46.1, U12.10
unnamed: C46.2, R48.2
unnamed: JP89.1, R50.2
unnamed: JP89.3, R49.2
unnamed: C51.1, U13.12
unnamed: C50.1, U13.10
unnamed: C50.2, R52.2
unnamed: JP96.1, R54.2
unnamed: JP96.3, R53.2
unnamed: C55.1, U14.12
unnamed: C54.1, U14.10
unnamed: C54.2, R56.2
unnamed: JP103.1, R58.2
unnamed: JP103.3, R57.2
unnamed: C59.1, U15.12
unnamed: C58.1, U15.10
unnamed: C58.2, R60.2
unnamed: JP110.1, R62.2
unnamed: JP110.3, R61.2
unnamed: C63.1, U16.12
unnamed: C62.1, U16.10
unnamed: C62.2, R64.2
unnamed: JP117.1, R66.2
unnamed: JP117.3, R65.2
unnamed: C67.1, U17.12
unnamed: C66.1, U17.10
unnamed: C66.2, R68.2
unnamed: JP124.1, R70.2
unnamed: JP124.3, R69.2
unnamed: C71.1, U18.12
unnamed: C70.1, U18.10
unnamed: C70.2, R72.2
unnamed: JP131.1, R74.2
unnamed: JP131.3, R73.2
unnamed: C75.1, U19.12
unnamed: C74.1, U19.10
unnamed: C74.2, R76.2
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

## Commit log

2018-02-16 checklist changes
    [Qwiic_Grideye.brd, Qwiic_Grideye.sch]
2018-02-19 Post double check changes
    [Qwiic_Grideye.brd, Qwiic_Grideye.sch]
2018-02-19 ordered protos
    [Qwiic_Grideye.GBL, Qwiic_Grideye.GBO, Qwiic_Grideye.GBS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]
2018-02-20 updated i2c address
    [Qwiic_Grideye.brd, Qwiic_Grideye.sch]
2018-03-07 post checklist changes
    [Qwiic_Grideye.brd, Qwiic_Grideye.sch]
2018-03-09 moved to origin
    [Qwiic_Grideye-Panel_v10.brd]
2018-03-09 created panel v10
    [Qwiic_Grideye-Panel_v10.brd]

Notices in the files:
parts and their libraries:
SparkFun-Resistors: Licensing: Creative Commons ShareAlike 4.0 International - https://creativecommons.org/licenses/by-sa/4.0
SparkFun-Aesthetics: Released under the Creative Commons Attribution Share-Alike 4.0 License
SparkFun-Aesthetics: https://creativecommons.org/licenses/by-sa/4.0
